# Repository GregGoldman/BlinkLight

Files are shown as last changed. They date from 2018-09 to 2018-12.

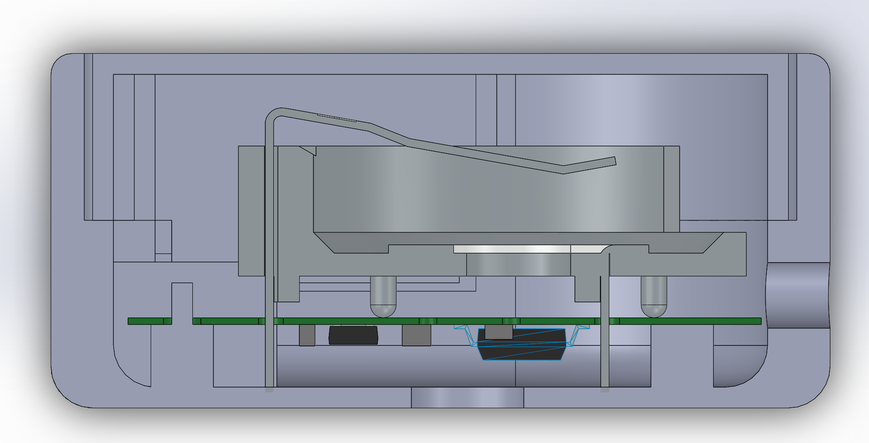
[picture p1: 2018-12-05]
Mechanical/Final Design/Photos/Assembly_Cross_Section.PNG

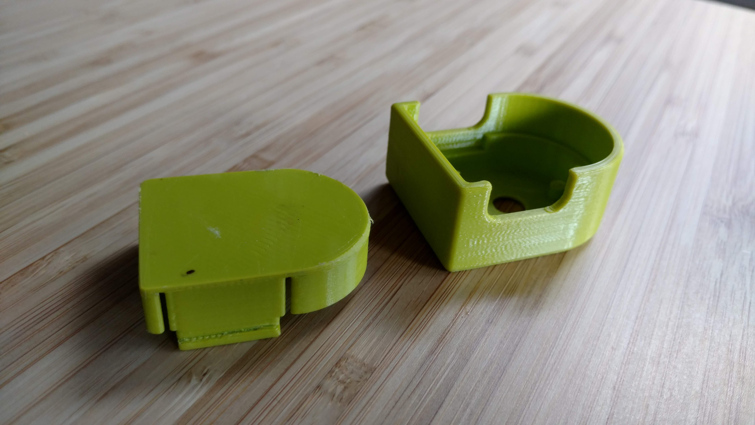
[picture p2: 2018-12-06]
Mechanical/Final Design/Photos/Final Case.jpg

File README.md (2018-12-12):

# BlinkLight
A small project for BME 590: Medical Instrumentation Design
Greg Goldman, ghg3@duke.edu

Project details are copied from https://github.com/mlp6/Fundamentals-BME-Design/blob/master/PrototypingSkills/VariableLightF18.md
There are a few weird commits around the end of October as I was using a loaner computer until I got mine repaired.

Final Specs:
-------------------------------------------------------------
Outer Dimensions: 1.510 x 1.870 x 0.850 inches

Weight: 1.15 ounces

Cost: $5.81 (including batteries, not including board and 3D-printed case)

Battery Life (when using two CR2430 batteries in series):

Asleep: 9232.5 hours = 384.7 days

Low:    67.2   hours = 2.8   days

Medium 	43.2   hours = 1.8   days

High	25.2   hours = 1.05  days

Flash	37.6   hours = 1.57  days (assuming average of 4 and 13 mA)

The design specs say use 1 battery up to 9 V. If you consider each CR2430
to be a one cell in a two-cell battery which is composed of two CR2430s taped
together, then it's only one battery ;)

Improvements:
-------------------------------------------------------------
Use a LDO which regulates to 2.7 V (ATTiny 85 minimum operating voltage)
so that I could use a single 3V CR2430 or similar battery and waste less power 
through the regulator. I had chosen a 3.3 V regulator because the LED had a 
voltage drop of 3.2 V, but I could likely find a similar one with a smaller voltage drop.

The layout could be improved. The placement of the LED was originally based on trying to model
the case like the Millenium Falcon, but it looked too thick to be satisfactory. As such, the 
LED leads and corresponding traces are longer than they need to be. 

Using a battery with a smaller diameter would have allowed for a smaller overall design.
The primary restriction was the size of the battery holder.

Final important documents:
-------------------------------------------------------------
Schematic and E-CAD photos: \BlinkLight\Electrical\FINAL OUTPUTS
Mechanical photos and drawings: \BlinkLight\Mechanical\Final Design

# Design Skills Project (Variable Light Intensity)

## Functional Specifications
* LED light that is button-activated to switch between the following operating modes:
  1. `Off`
  1. `Brightest`
  1. `Intermediate Brightness`
  1. `Least Bright`
  1. `Flashing @ 2 Hz`
* Self-contained device with LED and button exposed.
* Extra credit possibilities:
  + Battery life indicator
  + Waterproof enclosure
  + You tell us!

## Constraints
* Run on single battery up to 9 V
* Electronics connected to a single PCB (can be single- or double-sided)
* Cannot weight more than 1 lb
* Cannot have a single dimension > 6 in
* Cannot cost more than $50 to duplicate unit
* Battery must be easily replaceable

## Evaluation
* Minimize weight
* Minimize size
* Maximize `Brightest` mode
* Minimize power draw / maximize battery life
* Survive 3 foot drop with battery installed

* Create-and-maintain a GitHub project repository to maintain version history of:
  + Mechanical CAD (PDFs + more)
  + Electronic CAD (PDFs + more)
  + Software
  + Testing data
  + Design history / notes
  + Specification sheets
  + Usage notes (`README.md`)
  + Kanban board / Issues / Milestones

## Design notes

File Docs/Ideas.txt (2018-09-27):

Potentiometer to vary brightness
Potentiometer to vary flashing speed
Vary flashing duty cycle?
Water proof case
Battery life indicator (probably requires too much power... 
	Although if using a microcontroller, could PWM a code to the LED to indicate)
Sounds?
Different battery options?
rechargeable?

Make the housing fit on a keychain!

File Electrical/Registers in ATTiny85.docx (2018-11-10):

Configuring the pin:

- Each port consists of 3 register bits:
  - DDxn: accessed at the DDRx io address
    - Selectes direction of pin. If written to one, configured as output pin. If written as zero, configured as input pin

We have that PB4 is our LED (output) and PB3 is our button pin (input)

So we want:

DDRB = 0b00010000

  - PORTxn: accessed at the PORTx io address
    - If PORTxn is written to 1 when configured as input, pullup resistor is activated. Must be written to 0 to disable.
    - If portxn is written to 1 when configured as output, the pin is driven high
  - PINxn: accessed at the PINx io address
    - Writing a one to Pinxn toggles the value of portxn independent of ddrxn. The SBI instruction can be used to toggle one single bit in a port

10.4.2: PORTB – Port B Data Register : for choosing pullup/pulldown etc

We want the pin we are using for the button and led to be pulldown, and we want the pins for all others unused to be pull up

Turn off the pullup resistor for pin 3, and turn it off for the led pin(4) but leave them on for all the others. If we turn the pullup resistor on for pin 4 when pin 4 is configured as an output, it will be driven high.

PORTB = 0b11100111;

10.4.3 DDRB – Port B Data Direction Register

DDRB = 0b00010000; (set pin PB4 to output, all others to inputs)

10.4.4 PINB – Port B Input Pins Address : changing value of a bit toggles value of Portxn. Don’t touch this, or simply do:

PINB = 0b0000000

See page 57 for unused pins. Best to set the internal pullup.

Interrupts:

See page 48->

- GIMSK
  - General interrupt mask register

Bits 7, 4:0 are reserved

Bit 6: INT0, external interrupt request 0 enable (DON’t TOUCH THIS)

Bit 5: PCIE: Pin change interrupt enable

When set to one, and the I-bit in status register (SREG) is set to one (call sei()), any change enabled on PCINT[5:0] will cause an interrupt

GIMSK = 0b00100000

- PCMSK
  - pin change mask register
  - PCMSK register controls which pins contribute to the pin change interrupts on PCINT [5:0]

bits 7:6 are reserved

bits 5:0 select whether a pin change interrupt is enabled on the corresponding pin

if bit 5 of GIMSK is 1, then these overall are enabled.

Enable bit 3!!!! For button 😊

PCMSK = 0b00001000

The specification of falling, rising, or low can be set according to the MCU Control register, MCUCR. Recognition of interrupts as rising/falling on INT0 requires an I/O Clock… ☹ see page 23

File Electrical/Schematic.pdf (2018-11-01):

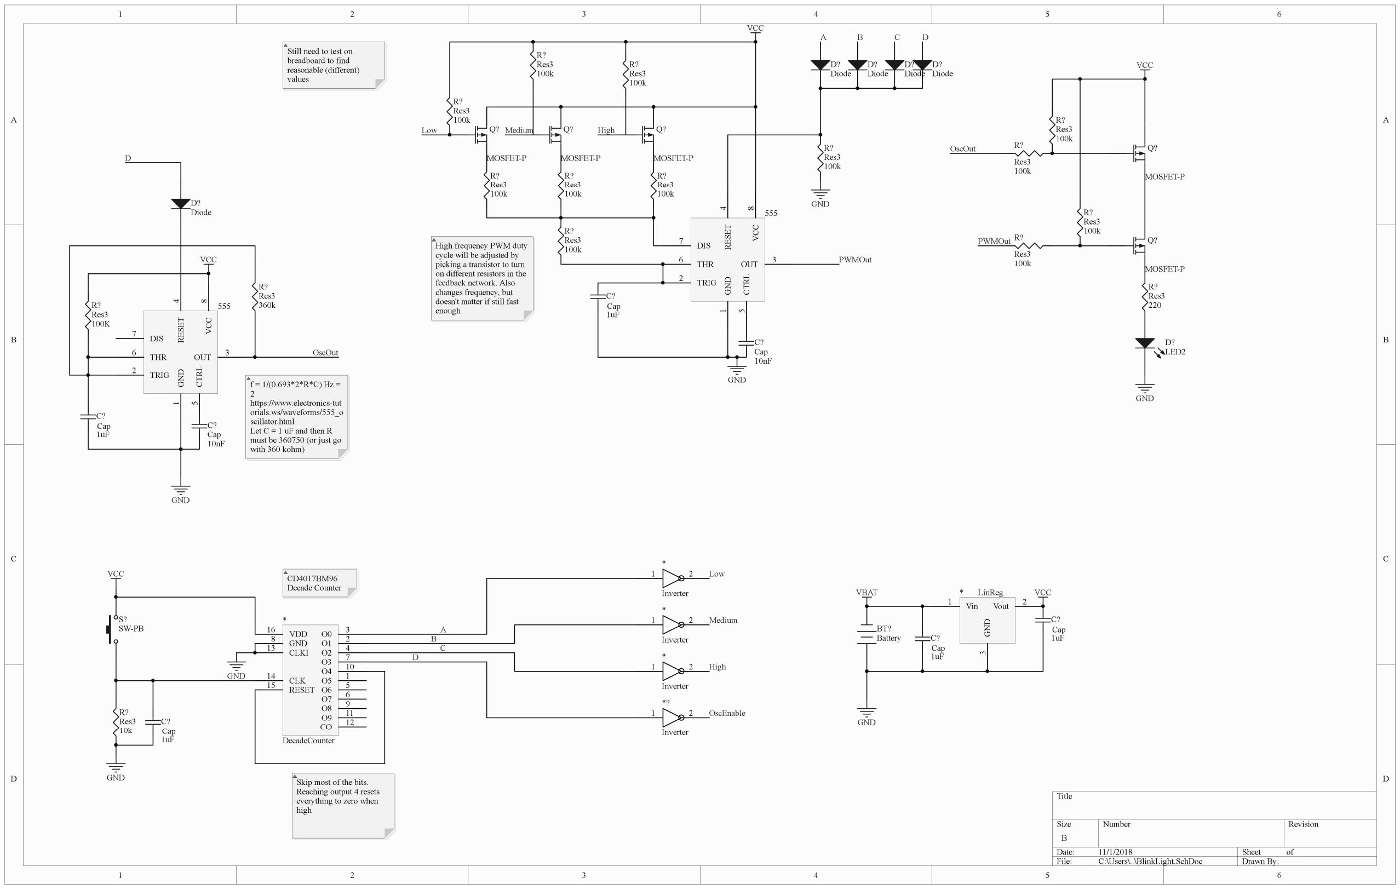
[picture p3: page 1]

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
Title

Size | Number | | Revision
B
Date: | 11/1/2018 | Sheet | of
File: | C:\Users\..\BlinkLight.SchDoc | Drawn By:

TRIG 2

OUT 3 RESET

# 4 CTRL

5

THR 6

DIS 7 | VCC

# 8 GND

1

555

1uF

C?
Cap

10nF

C?
Cap

GND

D?
LED2

S?
SW-PB

10k

R?
Res3

VCC

GND

GND

OscOut

BT?
Battery

VBAT

GND

360k

R?
Res3

100K

R?
Res3

1uF

C?
Cap

1 2

*

Inverter

1 2

*

Inverter

1 2

*

Inverter

VCC

CLK 14

CLKI 13

RESET 15

O0 | 3
O1 | 2
O2 | 4
O3 | 7
O4 | 10
O5 | 1
O6 | 5
O7 | 6
O8 | 9
O9 | 11
CO | 12

VDD 16
GND 8

*

DecadeCounter

GND

1 2

*?

Inverter

Low

Medium

High

OscEnable

TRIG 2

OUT 3 RESET

# 4 CTRL

5

THR 6

DIS 7 | VCC

# 8 GND

1

555

100k

R?
Res3
100k

R?
Res3

100k

R?
Res3

10nF

C?
Cap

GND

1uF

C?
Cap

Q?

MOSFET-P

Q?

MOSFET-P

Q?

MOSFET-P

Low | Medium | High

100k

R?
Res3

PWMOut

220

R?
Res3

Q?

MOSFET-P

PWMOut

Q?

MOSFET-P

100k

R?
Res3

OscOut

100k

R?
Res3

100k

R?
Res3

100k

R?
Res3

VCC

Vout | 2 Vin 1 | GND

3

* | LinReg | VCC

1uF

C?
Cap

1uF

C?
Cap

100k

R?
Res3

100k

R?

Res3

100k

R?

Res3 100k

R?
Res3

GND

VCC

D

D?
Diode

D

D?
Diode

D?
Diode

D?
Diode

D?
Diode
A | B | C | D

C

B

A

f = 1/(0.693*2*R*C) Hz =
2
https://www.electronics-tutorials.ws/waveforms/555_o
scillator.html
Let C = 1 uF and then R
must be 360750 (or just go with 360 kohm)

Skip most of the bits.
Reaching output 4 resets
everything to zero when
high

CD4017BM96
Decade Counter

High frequency PWM duty
cycle will be adjusted by
picking a transistor to turn on different resistors in the feedback network. Also
changes frequency, but
doesn't matter if still fast enough

Still need to test on
breadboard to find
reasonable (different)
values

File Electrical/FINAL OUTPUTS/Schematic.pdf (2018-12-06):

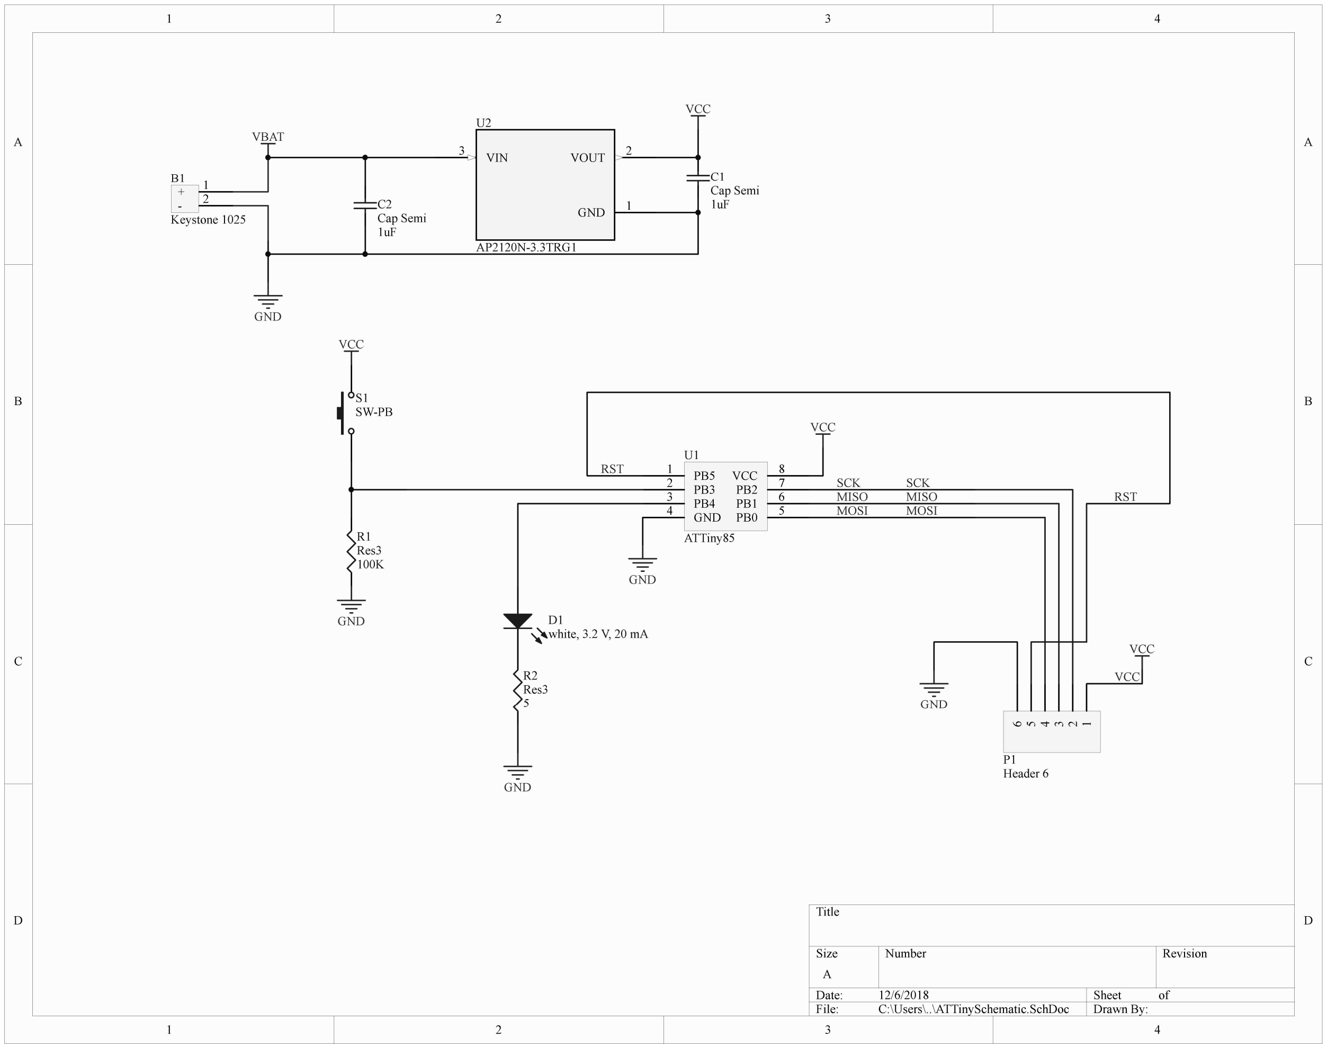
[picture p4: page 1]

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
Title

Size | Number | | Revision
A
Date: | 12/6/2018 | Sheet | of
File: | C:\Users\..\ATTinySchematic.SchDoc | Drawn By:

S1
SW-PB

100K

R1
Res3

VCC

GND

VBAT

GND

VCC

GND

5

R2
Res3

VCC

GND

MISO

SCK
RST

VCC

MOSI

GND

VCC

MISO
MOSI

SCK

RST | PB5 1
PB3 2
PB4 3
GND 4 | PB0 | 5
| PB1 | 6
PB2 | 7
VCC | 8

U1

ATTiny85

1uF

C2
Cap Semi

D1
white, 3.2 V, 20 mA
VIN 3 | VOUT | 2
GND | 1

U2

AP2120N-3.3TRG1

1uF

C1
+ | Cap Semi 1

2

B1

Keystone 1025

6

5

4

3

2

1

P1
Header 6

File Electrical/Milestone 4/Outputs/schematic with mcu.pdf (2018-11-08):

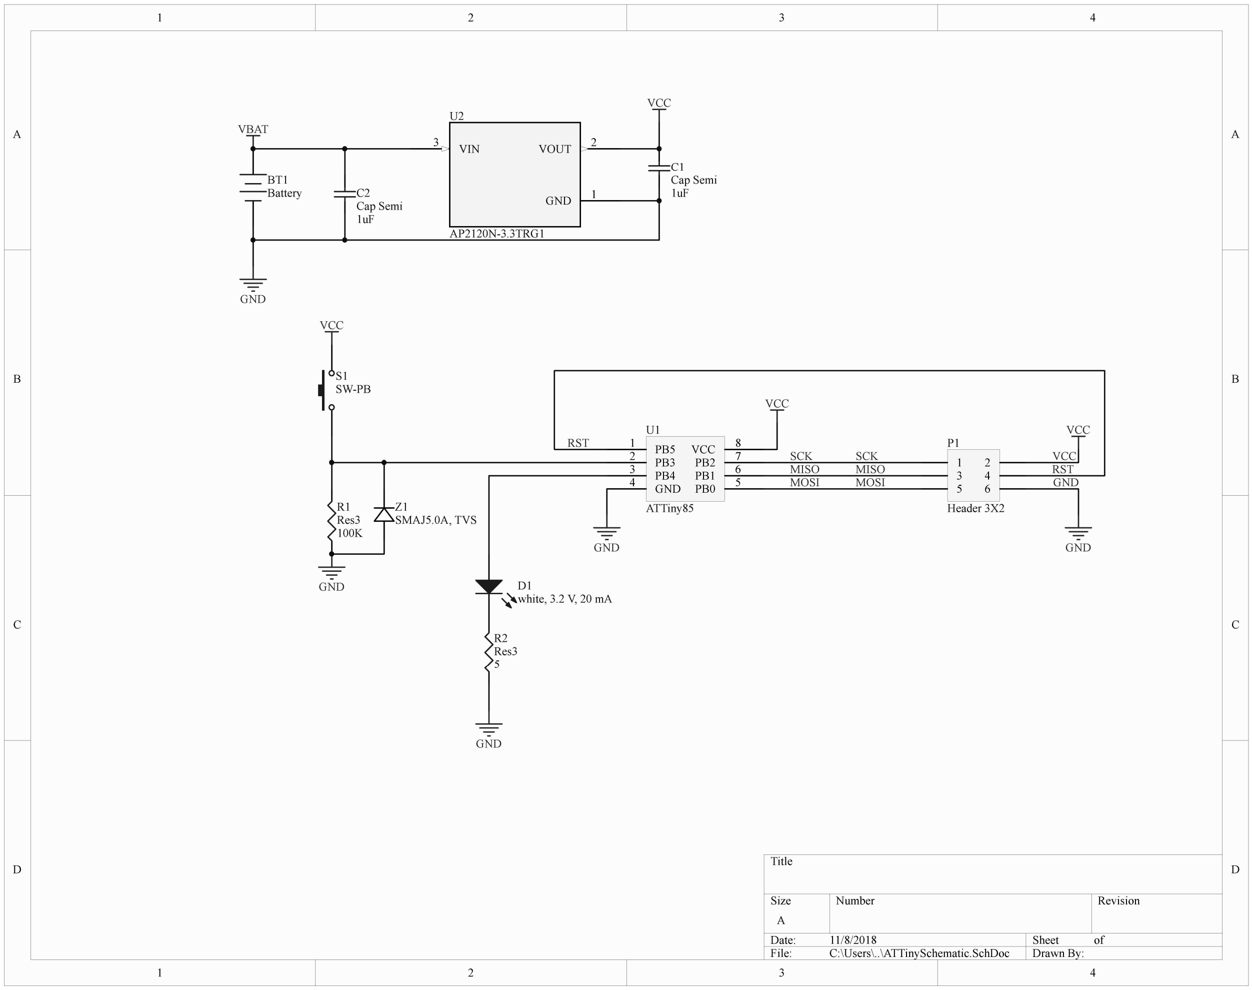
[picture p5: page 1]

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
Title

Size | Number | | Revision
A
Date: | 11/8/2018 | Sheet | of
File: | C:\Users\..\ATTinySchematic.SchDoc | Drawn By:

S1
SW-PB

100K

R1
Res3

VCC

GND

BT1
Battery

VBAT

GND

VCC

GND

5

R2
Res3

VCC

GND

1 2
3 4
5 6

P1

Header 3X2

MISO

SCK
RST

VCC

MOSI | GND

GND

VCC

MISO
MOSI

SCK

RST | PB5 1
PB3 2
PB4 3
GND 4 | PB0 | 5
| PB1 | 6
PB2 | 7
VCC | 8

U1

ATTiny85

1uF

C2
Cap Semi

Z1
SMAJ5.0A, TVS

D1
white, 3.2 V, 20 mA
VIN 3 | VOUT | 2
GND | 1

U2

AP2120N-3.3TRG1

1uF

C1
Cap Semi

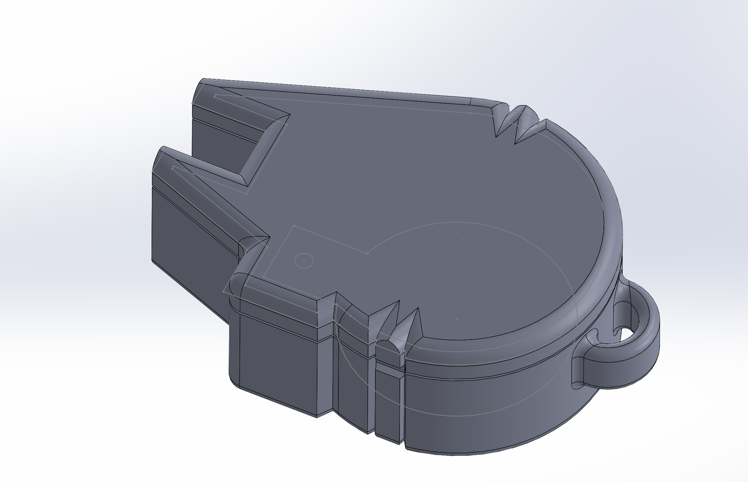
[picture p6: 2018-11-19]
Mechanical/first cad.PNG

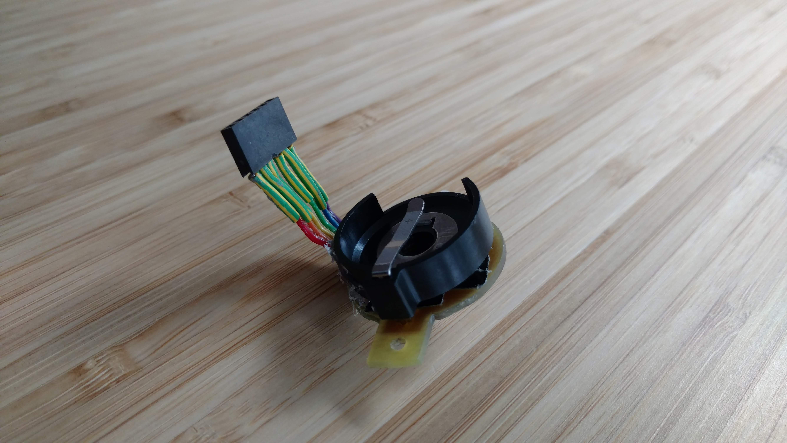
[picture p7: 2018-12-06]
Electrical/FINAL OUTPUTS/PCB Photo 2.jpg

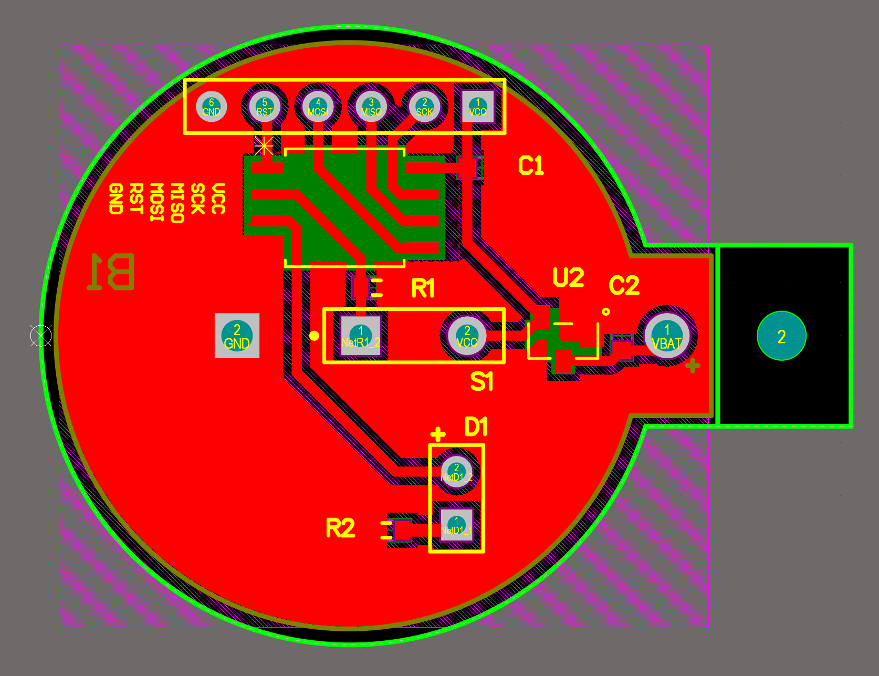
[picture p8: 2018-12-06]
Electrical/FINAL OUTPUTS/Board Top.PNG

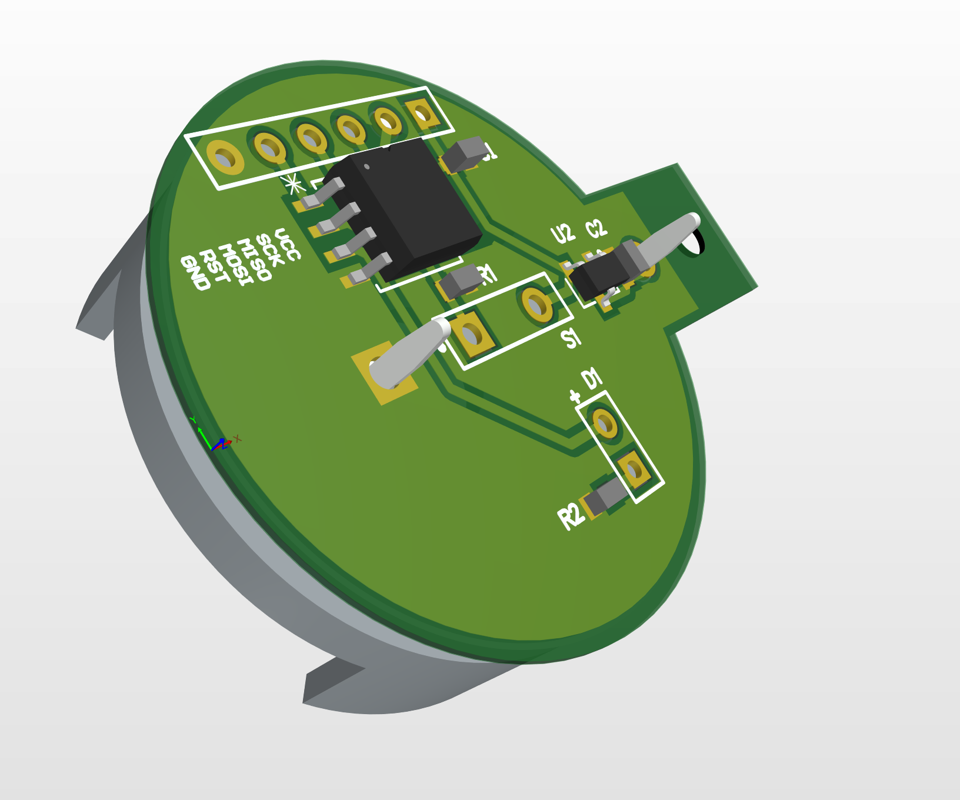
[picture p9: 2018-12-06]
Electrical/FINAL OUTPUTS/Board 3D.PNG

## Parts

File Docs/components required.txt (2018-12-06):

Components required:
ATTiny85
5 ohm resistor 0603 .25 W x1
100 kohm resistor 0603 0.1W x1
1 uF capacitor 0603 x 2 
Push Button

Linear Regulator 3.3 V
https://www.digikey.com/product-detail/en/diodes-incorporated/AP2120N-3.3TRG1/AP2120N-3.3TRG1DICT-ND/4505261

White led through hole (non-specific at this point)

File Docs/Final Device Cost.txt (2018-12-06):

Final Device Cost (Estimated):
ATTiny85:               $1.23
Linear Regulator 3.3 V: $0.28 
White LED:              $ 0.20
Push-Button:            $0.50
2x 0603 resistors:      $0.05 each
2x 0603 capacitors:     $0.05 each
2x CR2430 batteries:    $1.70 each

Total cost: not including board and 3D-printed case: $5.81

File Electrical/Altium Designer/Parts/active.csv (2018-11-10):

pn | description | package
INA726 | in amp | DIP-8
LF353 | op amp | DIP-8
2N7000 | N-chan MOSFET | TO-92
9B-16.000MEEJ-B | crystal oscillator (16 MHz)
7808 | 8V reg | TO-220
7905 | -5V reg | TO-220
7805 | 5V reg | TO-220, TO-92
7812 | 12V reg | TO-220
7912 | -12V reg | TO-220
7815 | 15V reg | TO-220
7915 | -15V reg | TO-220
LM723 | LDO reg
NE5532 | opamp | DIP-8
uA1458 | opamp | DIP-8
LM324 | quad opamp | DIP-14
LM741 | opamp | DIP-8
TL072 | opamp | DIP-8
TL074 | opamp | DIP-8
TL082 | opamp | DIP-8
TL084 | opamp | DIP-8
LF356 | opamp | DIP-8
LF353 | opamp | DIP-8
LF411 | opamp | DIP-8
LF412 | opamp | DIP-8
LM358 | opamp | DIP-8
LM301 | opamp | DIP-8
LM308 | opamp | DIP-8
LF386-1 | audio amp | DIP-8
LF383-3 | audio amp | DIP-8
INA126 | instrumentation amp | DIP-8
MCP6002 | RRIO omamp | DIP-8
ULN2803 | Darlington
ULN2003 | Darlington
TIP120 | NPN Darlington | TO-220
TIP127 | PNP Darlington | TO-220
556 | timer, dual 555 | DIP-14
555 | timer | DIP-8
LM311 | comparator | DIP-8
LM339 | comparator | DIP-8
LM393 | comparator | DIP-8
LM311 | comparator | DIP-8
MCP6541 | push-pull output omparator | DIP-8
TLC3702 | push-pull output comparator | DIP-8
MC1488 | driver
MAX232 | driver
MC1489 | driver
MCP3008 | A to D convertor
J109 | N-chan JFET
IRLI630 | N MOSFET 20V 6A
LM2917 | F-to-V converter
IRFZ44 | N FET
PIC16F676
ATTINY85
ATTINY10

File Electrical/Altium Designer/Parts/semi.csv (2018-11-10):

pn | description | package
2N3904 | NPN BJT | TO-92
2N3906 | PNP BJT | TO-92
PD204-6C | photodiode | T1 (3mm)
2N4401 | NPN transistor | TO-92
NTCLE100E3272JB0 | Thermistor, NTC
 | Green, red, misc LED T1 3/4 | T1 3/4 (5mm)
Adafruit 116 | Photoresistors CdS cell
FSM8JRT | momentary push button
1N914 | diode | DO-35
1N5226 | 3.3V Zener Diode | DO-35
1N4730 | 3.9V Zener Diode | DO-35
BZX79-C4V7 | 4.7V Zener | DO-35
1N5231 | 5.1V Zener | DO-35
1N5239 | 9.1V Zener | DO-35

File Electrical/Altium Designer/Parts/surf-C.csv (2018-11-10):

Value, Farad | mfr pn | voltage, temp | Tolerance, %
15 pF | GRM2165C1H150JZ01D | 50V C0G | 5%
22 pF | GRM2165C1H220JZ01D | 50V C0G | 5%
27 pF | GRM2165C1H270JZ01D | 50V C0G | 5%
33 pF | GRM2165C1H330JZ01D | 50V C0G | 5%
47 pF | GRM2165C1H470JZ01D | 50V C0G | 5%
68 pF | GRM2165C1H680JZ01D | 50V C0G | 5%
82 pF | GRM2165C1H820JZ01D | 50V C0G | 5%
100 pF | GRM2165C1H101JA01D | 50V C0G | 5%
120 pF | GRM2165C1H121JA01D | 50V C0G | 5%
150 pF | GRM2165C1H151JA01D | 50V C0G | 5%
180 pF | GRM2165C1H181JA01D | 50V C0G | 5%
220 pF | GRM216R71H221KA01D | 50V X7R | 10%
1 nF | GRM216R71H102KA01D | 50V X7R | 10%
10 nF | GRM216R71H103KA01D | 50V X7R | 10%
100 nF | GRM21BR71E104KA01L | 25V X7R | 10%
470 nF | GRM21BR71H474KA88L | 50V X7R | 10%
1 ?F | GRM21BR71A105KA01L | 10V X7R | 10%

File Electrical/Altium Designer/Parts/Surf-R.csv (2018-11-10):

Value, Ohm | mfr pn | Tolerance, %
0 | Yageo RC0805 JR-07 | 5%
1 | Yageo RC0805 JR-07 | 5%
1.2 | Yageo RC0805 JR-07 | 5%
1.5 | Yageo RC0805 JR-07 | 5%
2 | Yageo RC0805 JR-07 | 5%
2.7 | Yageo RC0805 JR-07 | 5%
3.3 | Yageo RC0805 JR-07 | 5%
4.3 | Yageo RC0805 JR-07 | 5%
5.1 | Yageo RC0805 JR-07 | 5%
6.8 | Yageo RC0805 JR-07 | 5%
8.2 | Yageo RC0805 JR-07 | 5%
10 | Yageo RC0805 JR-07 | 5%
12 | Yageo RC0805 JR-07 | 5%
15 | Yageo RC0805 JR-07 | 5%
20 | Yageo RC0805 JR-07 | 5%
27 | Yageo RC0805 JR-07 | 5%
33 | Yageo RC0805 JR-07 | 5%
43 | Yageo RC0805 JR-07 | 5%
51 | Yageo RC0805 JR-07 | 5%
68 | Yageo RC0805 JR-07 | 5%
82 | Yageo RC0805 JR-07 | 5%
100 | Yageo RC0805 JR-07 | 5%
120 | Yageo RC0805 JR-07 | 5%
150 | Yageo RC0805 JR-07 | 5%
200 | Yageo RC0805 JR-07 | 5%
270 | Yageo RC0805 JR-07 | 5%
330 | Yageo RC0805 JR-07 | 5%
430 | Yageo RC0805 JR-07 | 5%
510 | Yageo RC0805 JR-07 | 5%
680 | Yageo RC0805 JR-07 | 5%
820 | Yageo RC0805 JR-07 | 5%
1000 | Yageo RC0805 JR-07 | 5%
1200 | Yageo RC0805 JR-07 | 5%
1500 | Yageo RC0805 JR-07 | 5%
2000 | Yageo RC0805 JR-07 | 5%
2700 | Yageo RC0805 JR-07 | 5%
3300 | Yageo RC0805 JR-07 | 5%
4300 | Yageo RC0805 JR-07 | 5%
5100 | Yageo RC0805 JR-07 | 5%
6800 | Yageo RC0805 JR-07 | 5%
8200 | Yageo RC0805 JR-07 | 5%
10000 | Yageo RC0805 JR-07 | 5%
12000 | Yageo RC0805 JR-07 | 5%
15000 | Yageo RC0805 JR-07 | 5%
20000 | Yageo RC0805 JR-07 | 5%
27000 | Yageo RC0805 JR-07 | 5%
33000 | Yageo RC0805 JR-07 | 5%
43000 | Yageo RC0805 JR-07 | 5%
51000 | Yageo RC0805 JR-07 | 5%
68000 | Yageo RC0805 JR-07 | 5%
82000 | Yageo RC0805 JR-07 | 5%
100000 | Yageo RC0805 JR-07 | 5%
120000 | Yageo RC0805 JR-07 | 5%
150000 | Yageo RC0805 JR-07 | 5%
200000 | Yageo RC0805 JR-07 | 5%
270000 | Yageo RC0805 JR-07 | 5%
330000 | Yageo RC0805 JR-07 | 5%
430000 | Yageo RC0805 JR-07 | 5%
510000 | Yageo RC0805 JR-07 | 5%
680000 | Yageo RC0805 JR-07 | 5%
820000 | Yageo RC0805 JR-07 | 5%
1000000 | Yageo RC0805 JR-07 | 5%
2000000 | Yageo RC0805 JR-07 | 5%

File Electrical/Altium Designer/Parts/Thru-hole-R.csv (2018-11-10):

Value, Ohm | mfr pn | Tolerance, %
10 | Yageo CFR-25J | 5%
15 | Yageo CFR-25J | 5%
24.9 | Yageo MFR-25F | 1%
47 | Yageo CFR-25J | 5%
49.9 | Yageo MFR-25F | 1%
51 | Yageo MFR-25F | 1%
100 | Yageo MFR-25F | 1%
100 | Yageo CFR-25J | 5%
120 | Yageo CFR-25J | 5%
150 | Yageo CFR-25J | 5%
180 | Yageo CFR-25J | 5%
200 | Yageo MFR-25F | 1%
220 | Yageo CFR-25J | 5%
270 | Yageo CFR-25J | 5%
330 | Yageo CFR-25J | 5%
390 | Yageo CFR-25J | 5%
470 | Yageo CFR-25J | 5%
510 | Yageo CFR-25J | 5%
560 | Yageo CFR-25J | 5%
620 | Yageo CFR-25J | 5%
680 | Yageo CFR-25J | 5%
1000 | Yageo MFR-25F | 1%
1200 | Yageo CFR-25J | 5%
1500 | Yageo MFR-25F | 1%
1800 | Yageo MFR-25F | 1%
2000 | Yageo MFR-25F | 1%
2200 | Yageo MFR-25F | 1%
2700 | Yageo CFR-25J | 5%
3000 | Yageo MFR-25F
3300 | Yageo CFR-25J | 5%
3900 | Yageo CFR-25J | 5%
4700 | Yageo MFR-25F | 1%
5100 | Yageo CFR-25J | 5%
5600 | Yageo CFR-25J | 5%
7500 | Yageo CFR-25J | 5%
10000 | Yageo CFR-25J | 5%
12000 | Yageo CFR-25J | 5%
15000 | Yageo CFR-25J
18000 | Yageo CFR-25J
20000 | Yageo CFR-25J
22000 | Yageo CFR-25J | 5%
33000 | Yageo CFR-25J | 5%
47000 | Yageo CFR-25J | 5%
82000 | Yageo CFR-25J
100000 | Yageo CFR-25J | 5%
150000 | Yageo CFR-25J | 5%
180000 | Yageo CFR-25J | 5%
270000 | Yageo CFR-25J | 5%
330000 | Yageo CFR-25J
390000 | Yageo CFR-25J | 5%
470000 | Yageo CFR-25J | 5%
560000 | Yageo CFR-25J | 5%
680000 | Yageo CFR-25J | 5%
820000 | Yageo CFR-25J | 5%
1000000 | Yageo CFR-25J | 5%
3300000 | Yageo CFR-25J | 5%
10000000 | Yageo CFR-25J | 5%
33000000 | Yageo CFR-25J

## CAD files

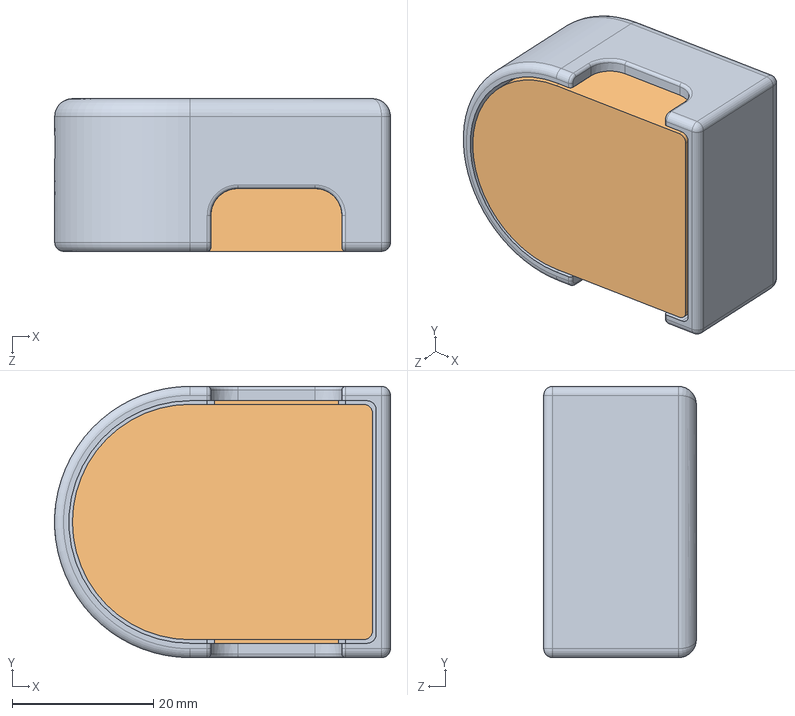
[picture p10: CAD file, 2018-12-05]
Mechanical/Final Design/snap_assem.SLDASM
47.5 x 38.4 x 21.6 mm
Base
Top
Board_2
keystone-PN1025-7_2
SOT23-3_2
Extruded_5
Extruded_5_2
Extruded_5_3
Extruded_5_4 x 2
8S2_2

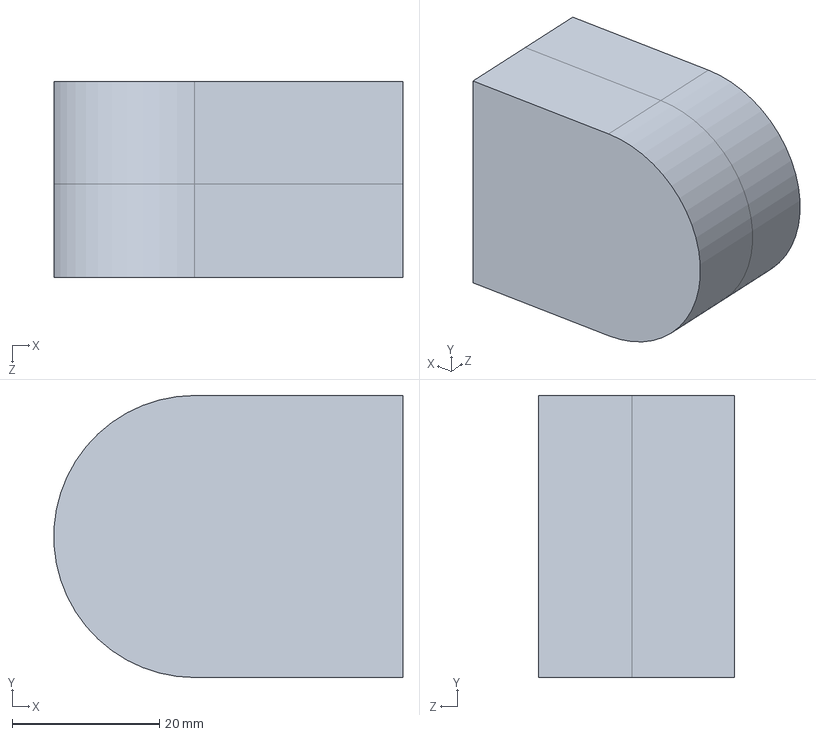
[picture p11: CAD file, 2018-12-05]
Mechanical/whole_case.SLDPRT
47.5 x 38.4 x 26.7 mm

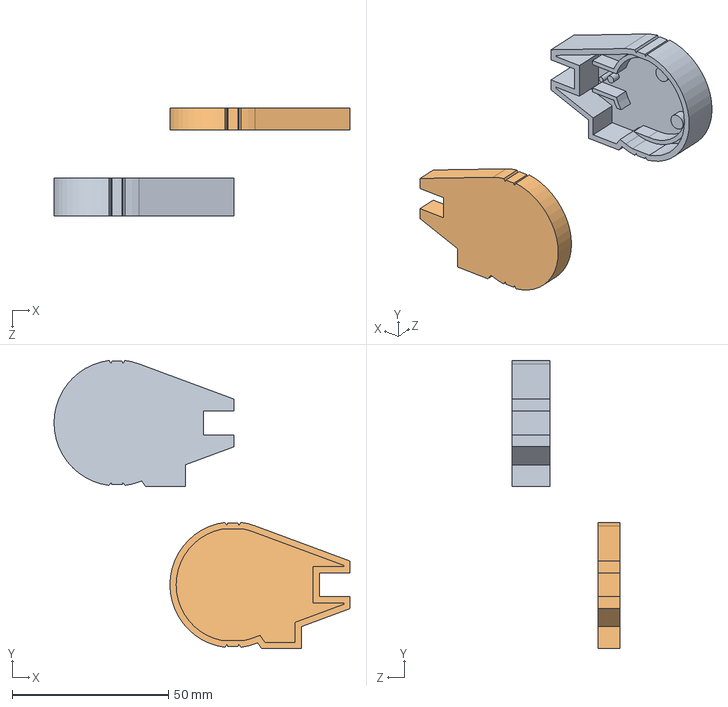
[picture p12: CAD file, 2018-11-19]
Mechanical/assembly test.SLDASM
94.8 x 92.2 x 34.6 mm
HousingTop
HousingBottom

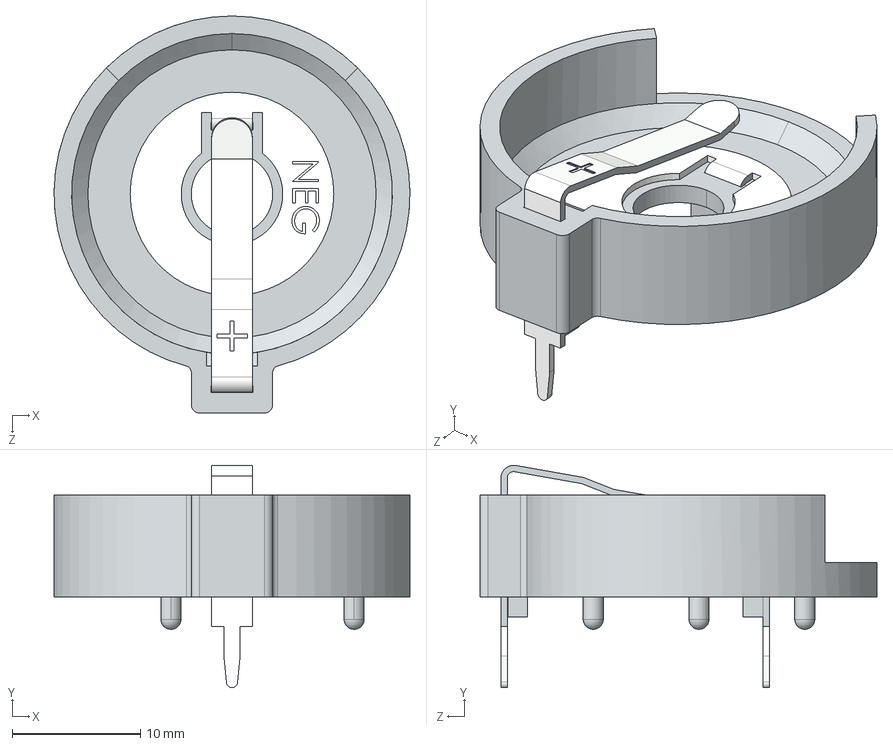
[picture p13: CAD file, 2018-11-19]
Electrical/Altium Designer/Parts/keystone-PN1025-7.STEP
27.8 x 17.3 x 31.0 mm

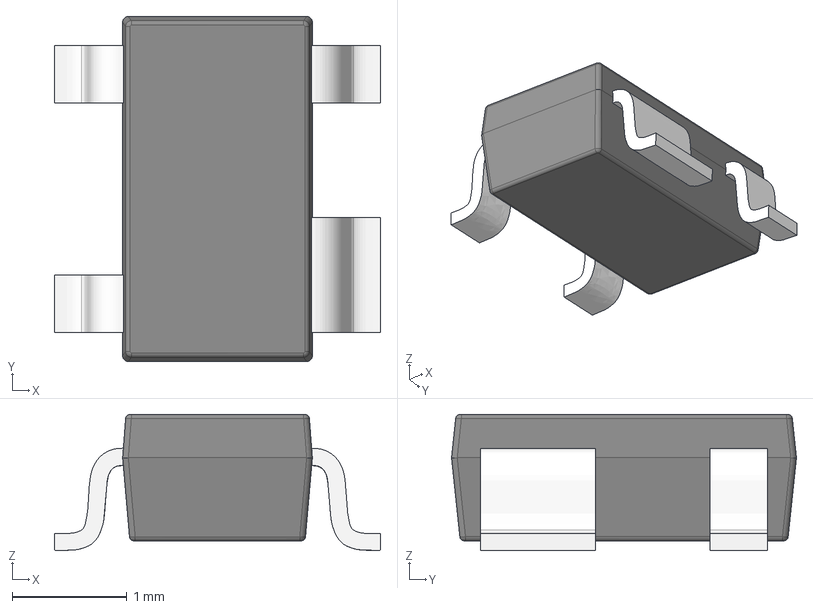
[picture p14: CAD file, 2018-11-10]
Electrical/Altium Designer/Parts/sot23-package-1.snapshot.6/SOT23-4.stp
2.84 x 3.00 x 1.18 mm

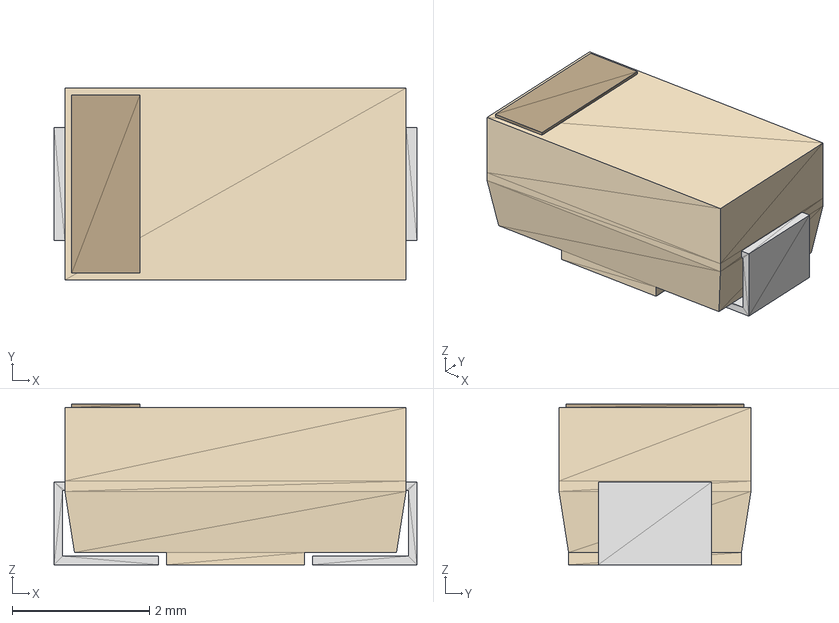
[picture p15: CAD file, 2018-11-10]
Electrical/Altium Designer/Parts/UL_SMAJ50A/SMASeries-M.stp
5.28 x 2.79 x 2.34 mm

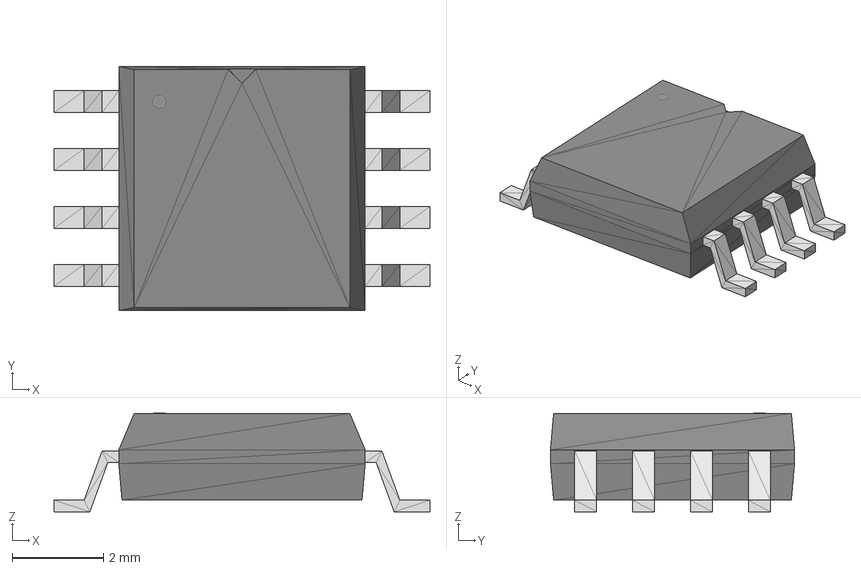
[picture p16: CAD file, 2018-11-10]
Electrical/Altium Designer/UL_ATTINY8520SUR step/STL/8S2-L.stp
8.25 x 5.36 x 2.16 mm

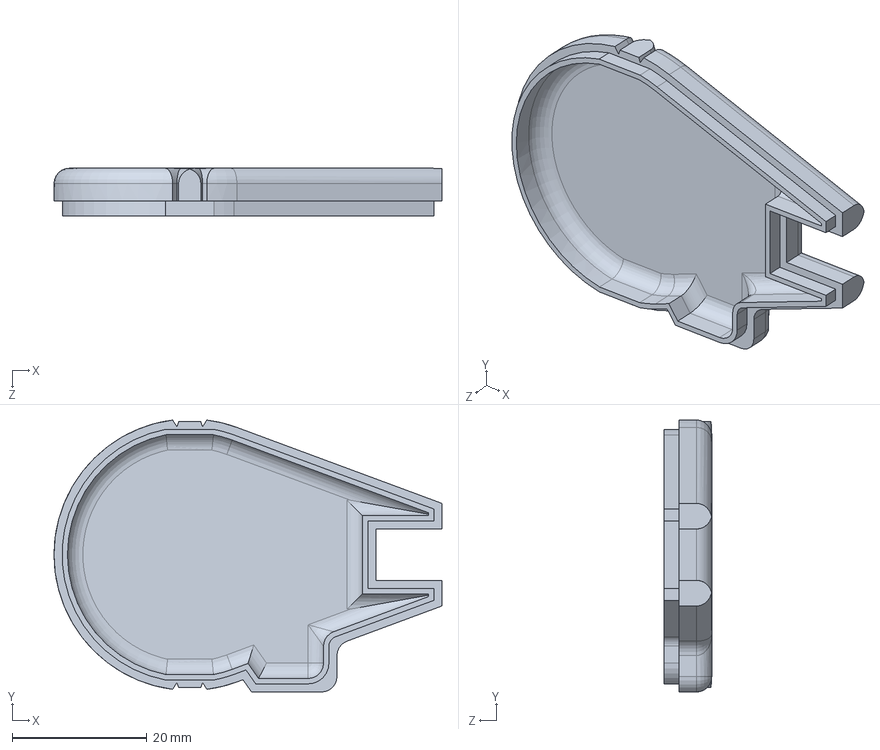
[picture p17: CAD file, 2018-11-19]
Mechanical/Millenium falcon design/HousingBottom.SLDPRT
57.7 x 40.4 x 7.08 mm

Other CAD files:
Mechanical/R1_1.sldasm
Mechanical/U2_1.sldasm
Mechanical/R2.sldasm
Mechanical/C1.sldasm
Mechanical/U1.sldasm
Mechanical/R1.sldasm
Mechanical/U2.sldasm
Mechanical/B1.sldasm
Mechanical/C2.sldasm
Mechanical/keystone-PN1025-7_2.sldprt
Electrical/Altium Designer/Parts/UL_SMAJ50A/SMASeries-L.stl
Electrical/Altium Designer/Parts/UL_SMAJ50A/SMASeries-L.stp
Electrical/Altium Designer/Parts/UL_SMAJ50A/SMASeries-M.stl
Electrical/Altium Designer/Parts/UL_SMAJ50A/SMASeries.stl
Electrical/Altium Designer/Parts/UL_SMAJ50A/SMASeries.stp
Electrical/Altium Designer/Parts/sot23-package-1.snapshot.6/SOT23-3.igs
Electrical/Altium Designer/Parts/sot23-package-1.snapshot.6/SOT23-3.stp
Electrical/Altium Designer/Parts/sot23-package-1.snapshot.6/SOT23-4.igs
Electrical/Altium Designer/Parts/sot23-package-1.snapshot.6/SOT23-5.igs
Electrical/Altium Designer/Parts/sot23-package-1.snapshot.6/SOT23-5.stp
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

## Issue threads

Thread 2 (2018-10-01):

Develop first draft of housing

GregGoldman, 2018-10-01:

GregGoldman, 2018-10-01:
Tried to close this with a commit, but my syntax was wrong

Closed 2018-10-01.

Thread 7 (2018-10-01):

Design 3d model draft of housing

GregGoldman, 2018-10-01:

ps178, 2018-11-21:
Could you clearly label your final CAD design that needs to be reviewed :) you have a lot of files under Mechanical

GregGoldman, 2018-11-23:
Yes, sorry about that! It seems to have split my PCB into a bunch of parts and crowded that folder.

It should be HousingTop.SLDPRT, HousingBottom.SLDPRT, BlinkLight_NewBat.SLDASM, and BlinkLight_NewBat.SLDDRW.
'first cad.PNG' is a screen clipping of the design all together

Closed 2018-12-12.

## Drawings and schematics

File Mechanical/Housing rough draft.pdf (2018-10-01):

# Housing

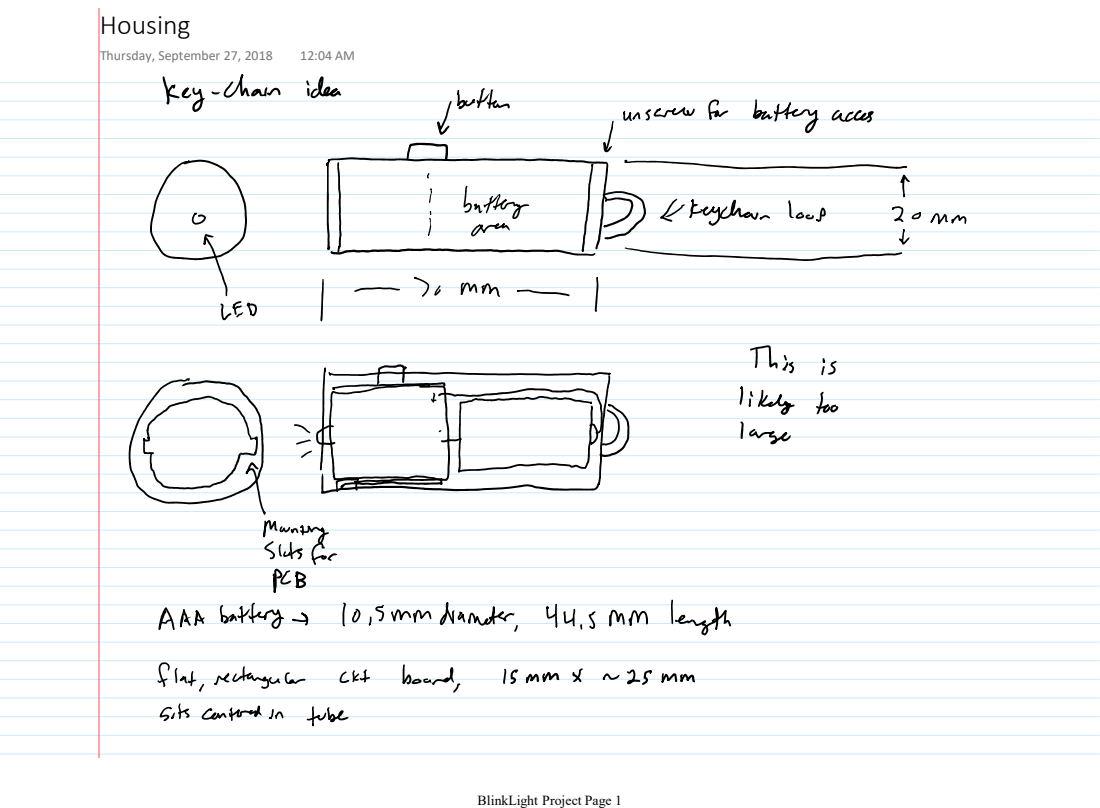
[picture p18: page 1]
Thursday, September 27, 2018

BlinkLight Project Page 1

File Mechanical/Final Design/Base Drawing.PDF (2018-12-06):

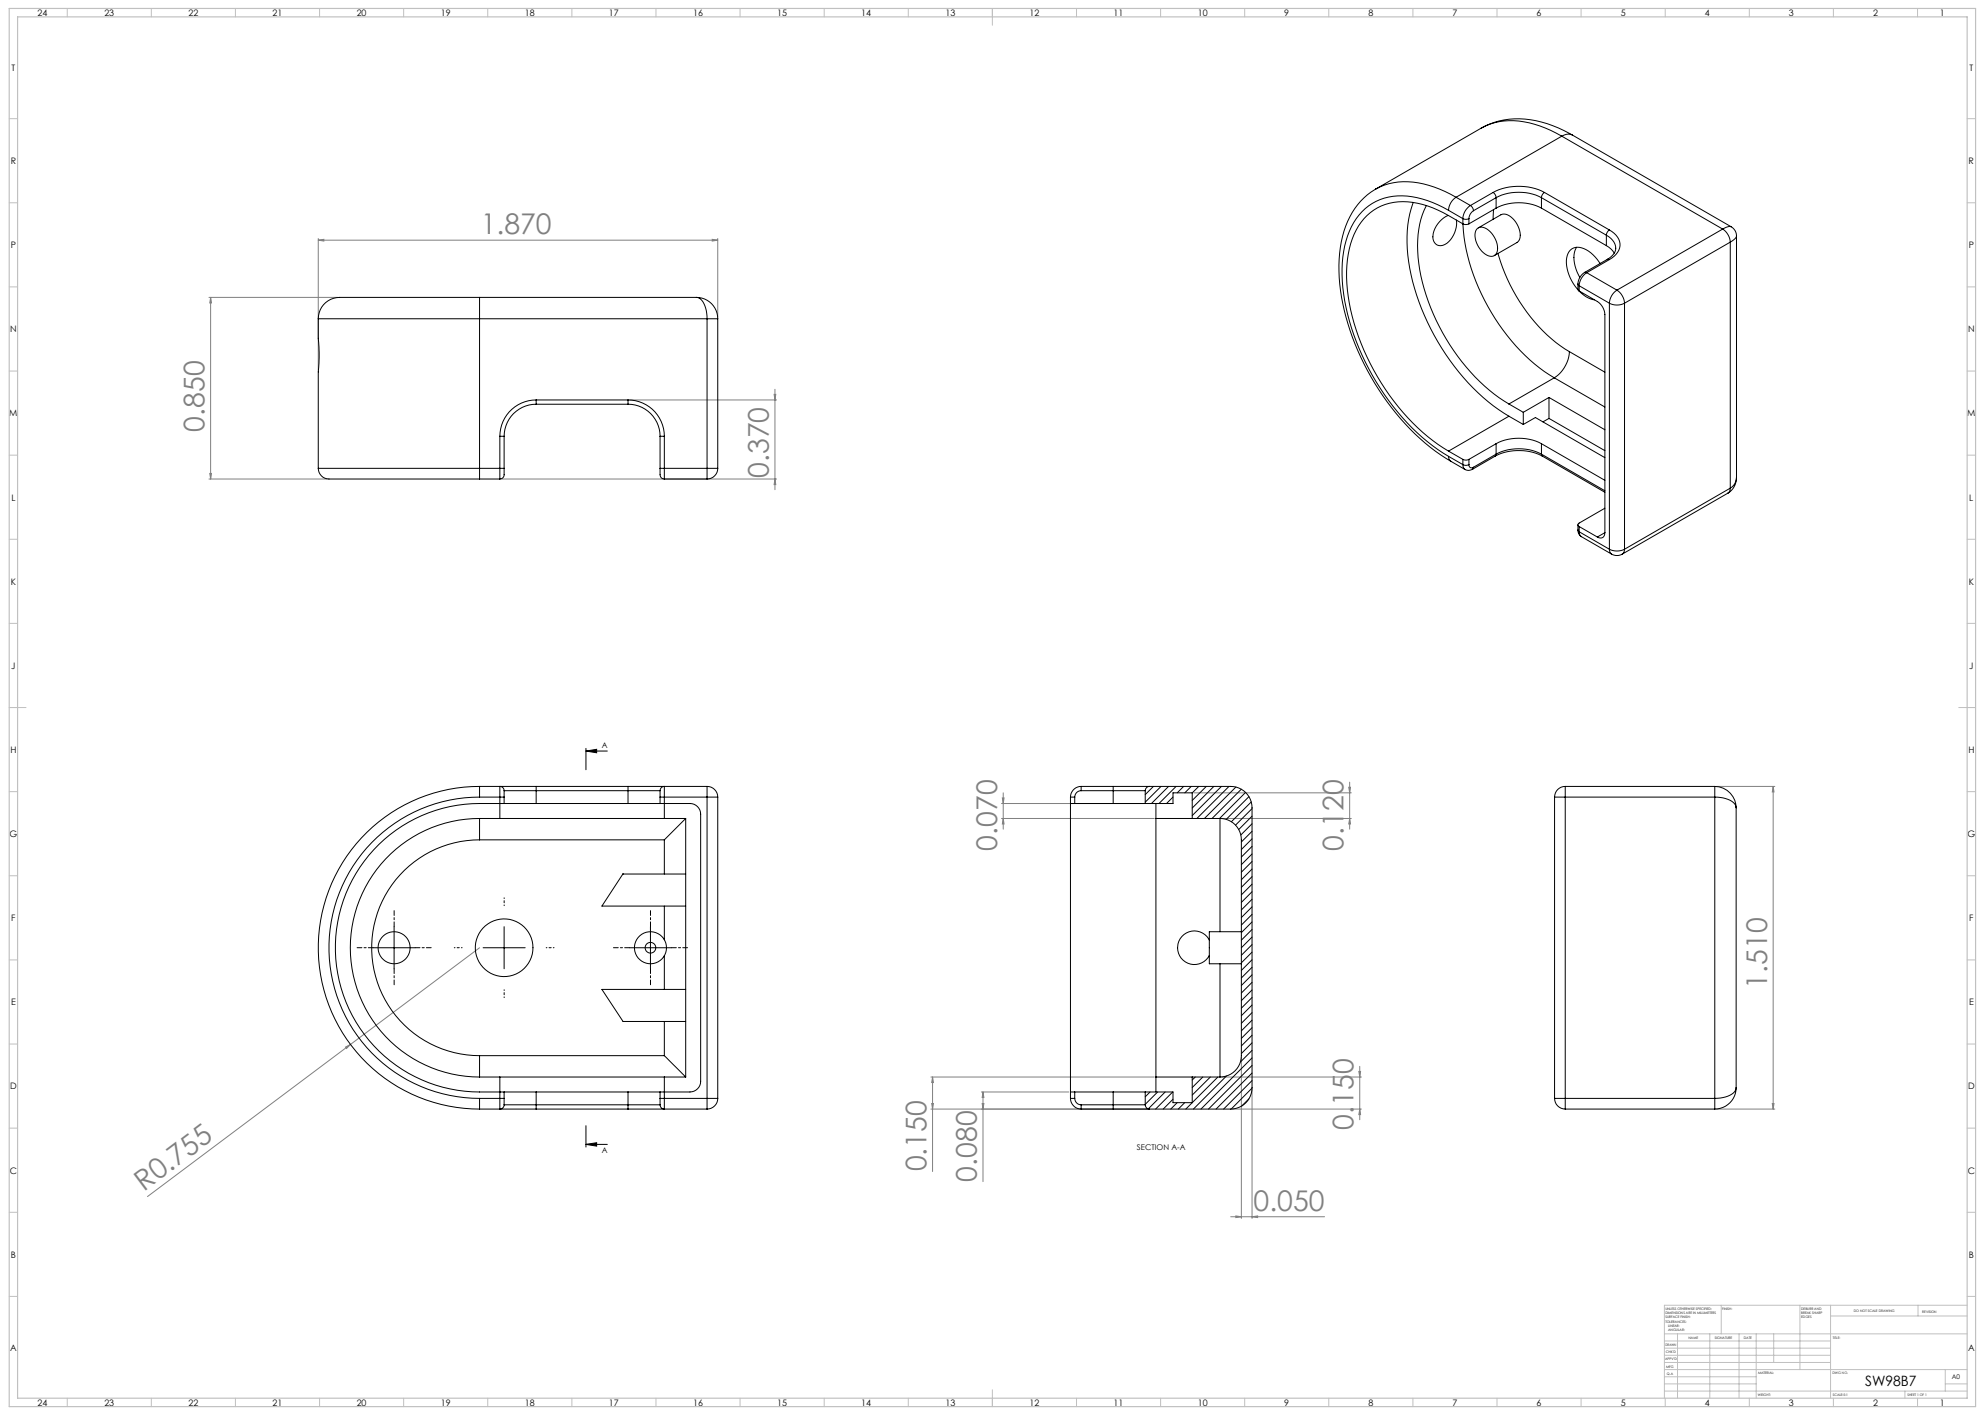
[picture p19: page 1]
SECTION A-A; FINISH:; DEBURR AND; BREAK SHARP; DO NOT SCALE DRAWING; REVISION; SCALE:5:1; SHEET 1 OF 1

UNLESS OTHERWISE SPECIFIED:
DIMENSIONS ARE IN MILLIMETERS
SURFACE FINISH:
TOLERANCES:
LINEAR:
ANGULAR:

NAME | SIGNATURE | DATE | | | | TITLE:

DRAWN
CHK'D
APPV'D
MFG
Q.A | | | | MATERIAL: | DWG NO. SW98B7 | A0

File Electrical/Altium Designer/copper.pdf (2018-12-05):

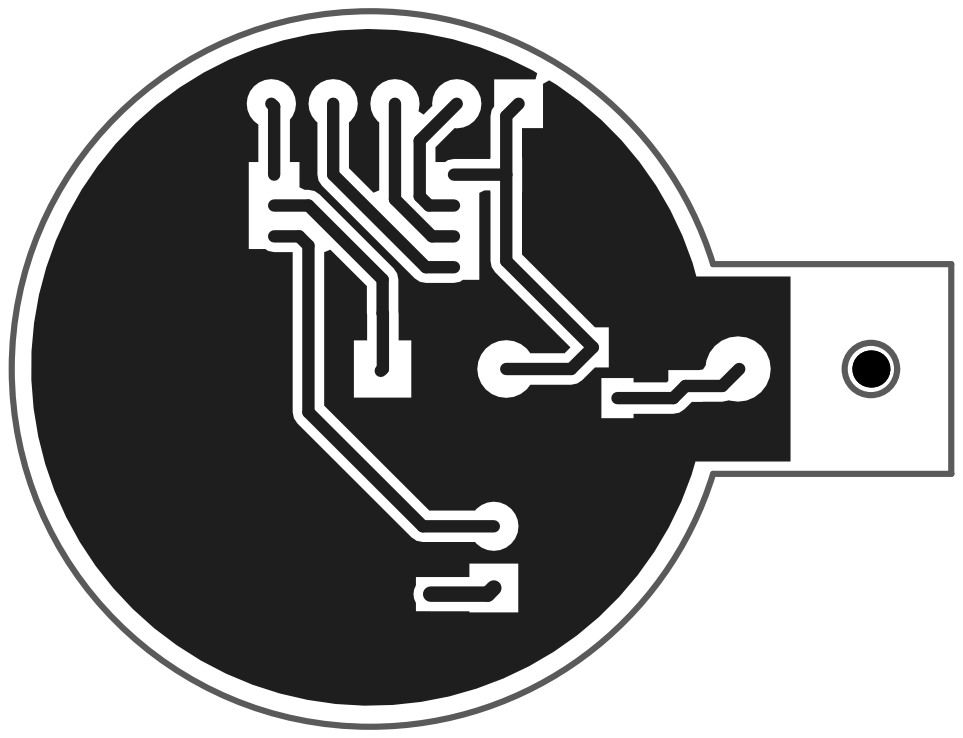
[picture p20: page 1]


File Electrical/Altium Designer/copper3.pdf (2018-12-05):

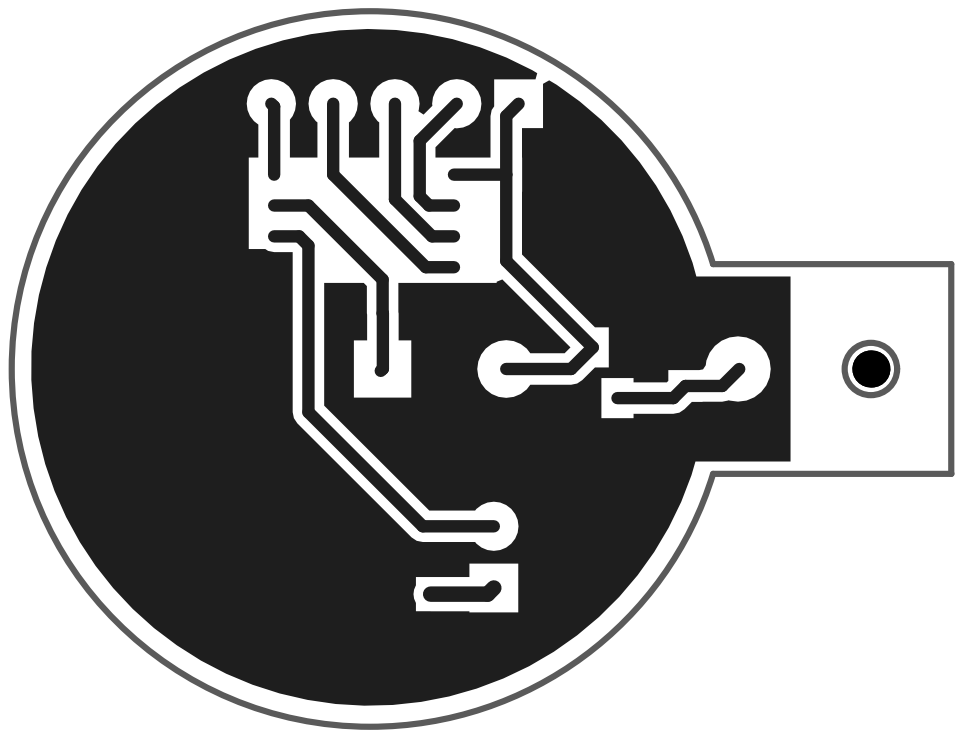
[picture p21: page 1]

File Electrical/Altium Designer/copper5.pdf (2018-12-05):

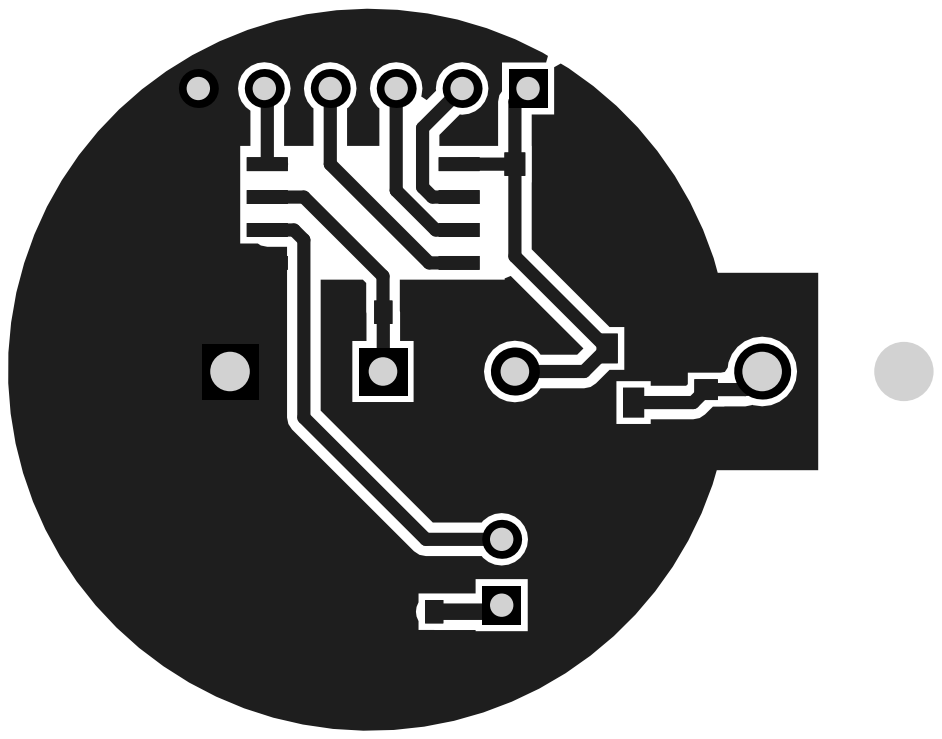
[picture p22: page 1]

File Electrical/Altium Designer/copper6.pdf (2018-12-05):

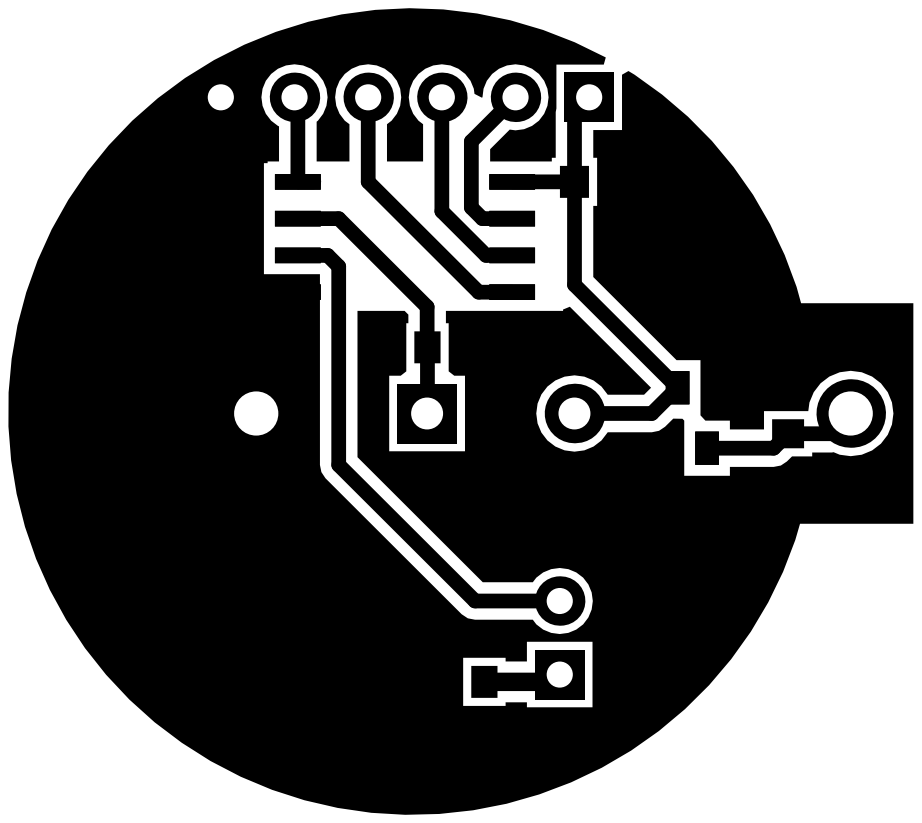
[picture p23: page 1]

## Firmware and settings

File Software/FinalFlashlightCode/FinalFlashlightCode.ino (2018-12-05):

/*
 * FinalFlashlightCode.ino
 * Greg Goldman and Jason Fischell
 * BME 590: Medical Instrumentation Design
 * Fall, 2018
 * 
 * This code operates a flashlight on an ATTiny85 processor at a clock speed of 8 MHz
 * It is capable of 5 modes: low, medium, high, flash at high, and off
 * When off, the processor is put to sleep, reducing its current draw from a few mA
 * to less than 50 uA.
 * 
 * It uses interrupts to record button inputs, and it has rudimentary software debounce 
 * built in.
 * 
 * A great challenge with the debounce was that the timer resets after going to sleep, so
 * it was hard to tell the time since the last press if the device had slept. This was solved
 * by implementing a delay of the bounce wait time before going to sleeep. 
 * 
 * All time variables are in microseconds because micros() works in the ISR, but millis doesn't
 * 
 * In an unsigned long, there are 2^32 bits, so I can count to about 4.295 billion microseconds,
 * or about 4295 seconds, which is about 2.98 days before the timer count can roll over
 * 
 * Related content can be found at https://github.com/GregGoldman/BlinkLight
 */

//Includes
#include <avr/io.h> 
#include <avr/interrupt.h> //https://www.nongnu.org/avr-libc/user-manual/group__avr__interrupts.html
#include <avr/sleep.h> //https://www.nongnu.org/avr-libc/user-manual/group__avr__sleep.html
//https://bigdanzblog.wordpress.com/2014/08/10/attiny85-wake-from-sleep-on-pin-state-change-code-example/
// how to put attiny to sleep

int LEDPIN = 4;
int BUTTONPIN = 3;
bool Flash = LOW;
volatile int State = 0;


volatile int pressCount = 0;
/*
   0: off
   1: low
   2: med
   3: high
   4: 2Hz blink at high intensity
*/

///online sources suggest to declare variables which go in the ISR as volatile
unsigned long bounceTime = 50000; // how long to wait to avoid bounce: 200 ms
volatile unsigned long now = 0; //current time
unsigned long lastFlashTime = 0; // previous time
volatile unsigned long lastPressedTime = 0;

void setup() {
  // sets PB4 to output, all others to inputs
  DDRB  = 0b00010000;

  //disable pullup on PB3 and PB4
  PORTB = 0b11100111;

  // set all outputs to low first (default, likely unecessary)
  PINB = 0b00000000;

  //disable interrupts during setup
  cli();
  // choose PB 3 for your interrupt pin
  PCMSK = 0b00001000;
  // globally stage change interrupts to be enabled (still requires sei())
  GIMSK = 0b00100000;

  ADCSRA &= ~_BV(ADEN);  // ADC off

  //enable interrupts after setup
  sei();
}

void loop() {
  // only increment the State at the top of the loop so it can't change during 
  // the Switch Tree or other inconvenient places
  if (pressCount > 0) {
    State += 1;
    if (State > 4) {
      State = 0;
    }
    pressCount = 0;
  }
  
  switch (State) {
    case 0:
      analogWrite(LEDPIN, 0);
      // the longest accurate microsecond delay is 16383 according to arduino.cc
      // as such, use delay() instead
      // this is one of the rare cases we are OK with a delay.
      delay(bounceTime/1000);
      set_sleep_mode(SLEEP_MODE_PWR_DOWN);
      sleep_enable();
      sleep_cpu();
      break;
    case 1:
      sleep_disable(); // not entirely sure this line is needed
      analogWrite(LEDPIN, 20);
      break;
    case 2:
      analogWrite(LEDPIN, 100);
      break;
    case 3:
      analogWrite(LEDPIN, 255);
      break;
    case 4:
      now = micros();
      if (now - lastFlashTime > 250000) {
        Flash = !Flash;
        lastFlashTime = now;
      }
      if (Flash) {
        analogWrite(LEDPIN, 255);
      }
      else {
        analogWrite(LEDPIN, 0);
      }
      break;
    default:
      analogWrite(LEDPIN, 0);
      break;
  }
}

//Pin Change Interrupt Request 0 (don't look at nested interrupts)
ISR(PCINT0_vect) {
  // This will trigger on both rising and falling by default
  // need to read the state of the pin to tell if rising
  now = micros();
  if (digitalRead(BUTTONPIN)) {
    if (now - lastPressedTime > bounceTime || State == 0) {
      pressCount += 1;
    }
  }
  lastPressedTime = micros();
}

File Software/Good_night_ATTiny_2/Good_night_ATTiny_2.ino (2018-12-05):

//Includes
#include <avr/io.h> // Not entirely sure what this does
#include <avr/interrupt.h> //https://www.nongnu.org/avr-libc/user-manual/group__avr__interrupts.html
#include <avr/sleep.h> //https://www.nongnu.org/avr-libc/user-manual/group__avr__sleep.html

//https://bigdanzblog.wordpress.com/2014/08/10/attiny85-wake-from-sleep-on-pin-state-change-code-example/
// how to put attiny to sleep

int LEDPIN = 4;
int BUTTONPIN = 3;
bool Flash = LOW;
volatile int State = 0;
volatile int lastState = 4;
/*
   0: off
   1: low
   2: med
   3: high
   4: 2Hz blink at high intensity
*/

unsigned long bounceTime = 200000;
volatile unsigned long t1 = 0; //current time
volatile unsigned long t2 = 0; // previous time
volatile unsigned long lastPressedTime = 0;

void setup() {
  // sets PB4 to output, all others to inputs
  DDRB  = 0b00010000;

  //disable pullup on PB3 and PB4
  PORTB = 0b11100111;

  // set all outputs to low first (default, likely unecessary)
  PINB = 0b00000000;

  //disable interrupts during setup
  cli();
  // choose PB 3 for your interrupt pin
  PCMSK = 0b00001000;
  // globally stage change interrupts to be enabled (still requires sei())
  GIMSK = 0b00100000;

  ADCSRA &= ~_BV(ADEN);  // ADC off

  //enable interrupts after setup
  sei();

}

void loop() {

  /*
     Because the timer resets whenever the attiny85 goes to sleep,
     I can't use the time difference to debounce from state 0

     The common case is that I'll press the button on State 4 (flash),
     and it will skip from zero (sleep) to 1 (low)

     It almost always only bounces once, which must be happening during
     the switch tree, so it jumps from State = 4 to State = 1;
     This jump from 4->0->1 must happen before another loop() completes.
     I know that the ATTiny85 is not getting to State = 0, going to sleep,
     and then waking back up on the bounce because I have a delayMicroseconds
     line inside of that case which should ignore that bounce.

     If I keep track of the last State called at the top of every loop,
     I'll know if the State has moved by more than 1 in the course of a
     single loop, which is the shortest amount of time for detection.
  */
  switch (State) {
    case 0:
      analogWrite(LEDPIN, 0);
      delayMicroseconds(bounceTime);
      set_sleep_mode(SLEEP_MODE_PWR_DOWN);
      sleep_enable();
      sleep_cpu();
      break;
    case 1:
      sleep_disable();
      if (lastState == 4){
        State = 0;
        break;
      }
      analogWrite(LEDPIN, 20);
      break;
    case 2:
      analogWrite(LEDPIN, 100);
      break;
    case 3:
      analogWrite(LEDPIN, 255);
      break;
    case 4:
      t1 = micros();
      if (t1 - t2 > 250000) {
        Flash = !Flash;
        t2 = t1;
      }
      if (Flash) {
        analogWrite(LEDPIN, 255);
      }
      else {
        analogWrite(LEDPIN, 0);
      }
      break;
    default:
      analogWrite(LEDPIN, 0);
      break;
  }
  lastState = State;
}

//Pin Change Interrupt Request 0 (don't look at nested interrupts)
ISR(PCINT0_vect) {
  // This will trigger on both rising and falling by default
  // need to read the state of the pin to tell if rising
  t1 = micros();
  if (digitalRead(BUTTONPIN)) {
    if (t1 - lastPressedTime > bounceTime || State == 0) {
      State = State + 1;
      if (State > 4) {
        State = 0;
      }
    }
  }
  lastPressedTime = micros();
}



void incrementState(){
  State+=1;
  if (State > 4){
    State = 0;
  }
}

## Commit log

2018-09-27 First ideas
    Updated circuit drafts, included an ideas document
2018-10-01 Add rough draft of housing
    closes (#2)
2018-10-28 Altium update
    Added some work on Altium. This folder is temporary and will be updated online until I get my normal computer back (killed my laptop, currently using a loner without git installed)
    [BlinkLight.PcbDoc, BlinkLight.PrjPCB, BlinkLight.SchDoc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]
2018-11-01 Uploaded schematic for circuit
2018-11-01 Final schematic before breadboard
2018-11-08 Added files for milestone 4
    schematic, parts list, code, layout
2018-11-10 Changed folder structure
    Updated lots of stuff after getting my computer back from HP repair center
    [8S2-L.stl, 8S2-L.stp, 8S2-M.stl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]
2018-11-19 milestone 5
    First draft of mechanical stuff. Need to get dimensions of button to make a hole for it
    [6058774336.sldasm, 6058774528.sldasm, 6058774720.sldasm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]
2018-12-05 final code and mechanical!
    Still need to clean up some folder structure
    [6058774336_1.sldasm, 6058774336_2.sldasm, 6058774528_1.sldasm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]
2018-12-05 File restructure
    [6058774336.sldasm, 6058774336_1.sldasm, 6058774336_2.sldasm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]
2018-12-06 Pretty much done... just have to weigh it
    [ATTinySchematic.SchDoc, Base Drawing.SLDDRW, BlinkLight.PcbDoc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]
